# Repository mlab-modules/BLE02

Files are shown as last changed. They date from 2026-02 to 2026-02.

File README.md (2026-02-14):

# BLE02 - Dual-Mode Bluetooth HCI Controller

BLE02 is a dual-mode Bluetooth Low Energy controller module based on the CC2564C HCI compatible chipset.  
The module provides UART (HCI) and PCM/I²S digital audio interface and is designed as a compact MLAB building block for integration with external MCU/MPU systems.

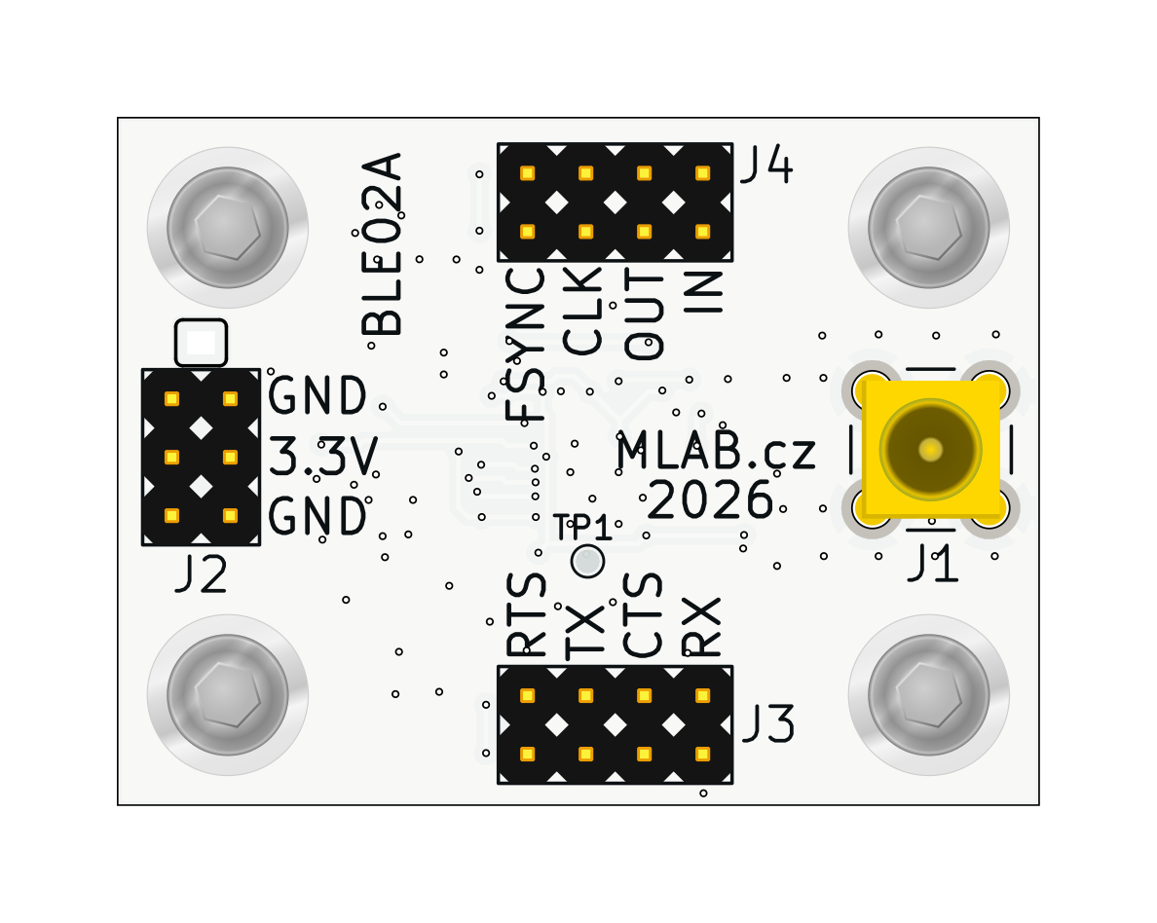
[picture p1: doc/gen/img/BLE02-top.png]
BLE02 top view


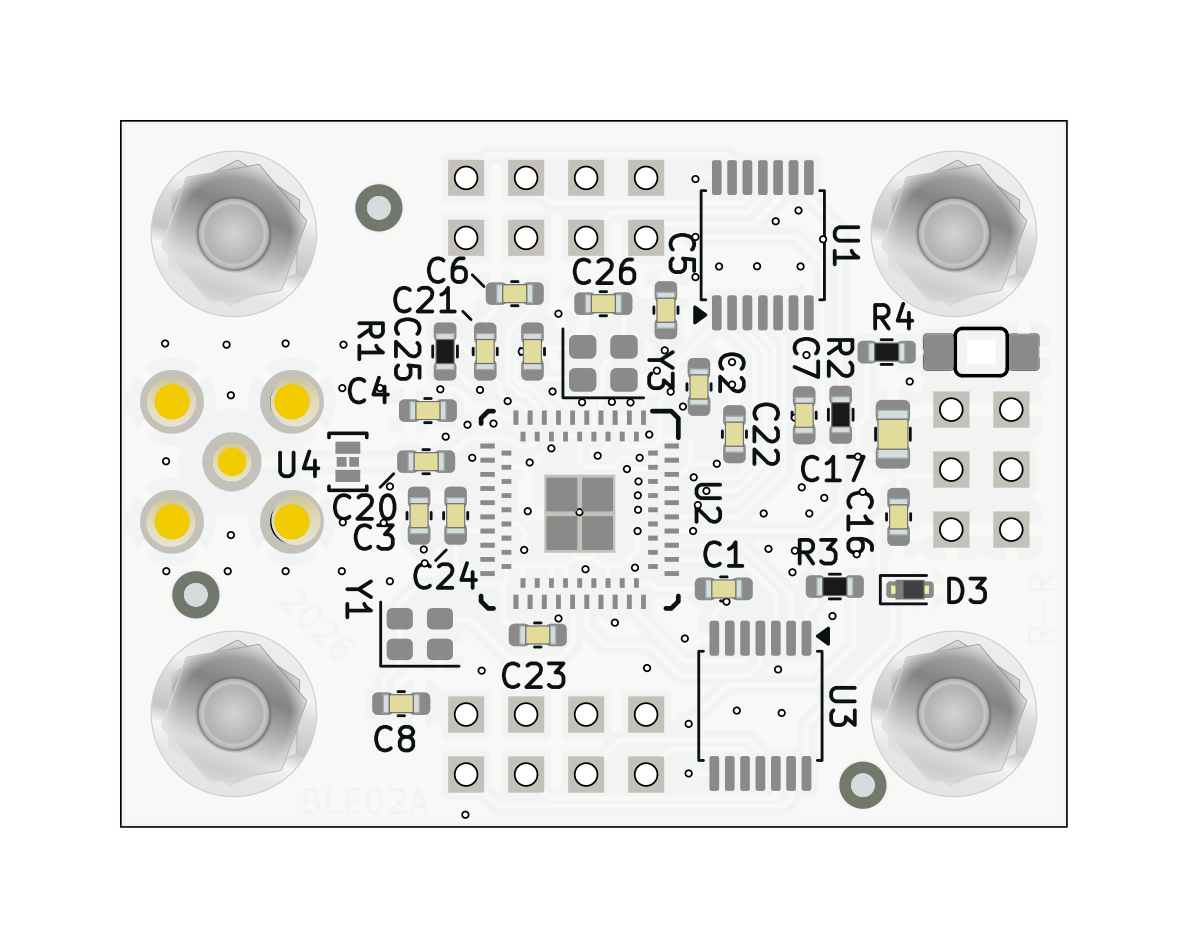
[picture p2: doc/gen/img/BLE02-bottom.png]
BLE02 bottom view


The RF section, clocks and power conditioning are implemented on-board. The host processor should handle the Bluetooth stack via HCI transport.

## Key Features

- Dual-mode Bluetooth controller (BR/EDR + LE, Bluetooth 5.1 compliant)
- HCI transport over UART (up to 4 Mbit/s)
- PCM / I²S digital audio interface
- Class 1 transmitter capability (up to +12 dBm)
- Integrated LDO regulator from 3.3V power source
- 26 MHz main crystal oscillator
- 32.768 kHz low-power clock oscillator
- 1.8 V I/O domain (level shifted to 3.3 V on module connectors)
- Single-ended 50 Ω RF interface on MCX connector

The module uses the chip in HCI mode. All higher Bluetooth layers must run on the host MCU.

## Electrical Parameters

### Supply

- **VCC (module input):** 3.3 V nominal
- On-board regulation:
  - CC2564C powered directly from power input
  - I/O domain: 1.8 V (generated internally, exposed as VDD_1V8)
- Typical consumption:
  - TX (GFSK, max power): ~100 mA
  - LE advertising: 200 µA average
  - Shutdown: less than 10 µA

## UART Interface (HCI)

- Transport: H4 (UART)
- Baud rate: 38.4 kbit/s to 4 Mbit/s
- Hardware flow control required (RTS/CTS)

The controller signals boot completion by asserting RTS low after reset.

## Audio Interface (PCM / I²S)

- PCM master or slave mode
- Up to 4.096 MHz bit clock
- Suitable for HFP, A2DP and other audio profiles

Note: Assisted modes (WBS, A2DP assist) cannot be used simultaneously with LE mode.

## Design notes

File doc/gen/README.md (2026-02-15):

# PCB

Board size: 40.13x29.97 mm (1.58x1.18 inches)

- This is the size of the rectangle that contains the board
- Thickness: 0.19 mm (7 mils)
- Material: FR4
- Finish: None
- Layers: 2
- Copper thickness: 35 µm

Solder mask: TOP / BOTTOM

- Color: Green

Silk screen: TOP / BOTTOM

- Color: White

Stackup:

Impedance controlled: YES

| Name | Type | Color | Thickness [µm]| Material | Er | Loss tan |
|---|---|---|---|---|---|---|
| F.SilkS | Top Silk Screen | | | | | |
| F.Paste | Top Solder Paste | | | | | |
| F.Mask | Top Solder Mask | Green | 10 | | | |
| F.Cu | copper | | 35 | | | |
| dielectric 1 | prepreg | | 100 | FR4 | 4.5 | 0.020 |
| B.Cu | copper | | 35 | | | |
| B.Mask | Bottom Solder Mask | Green | 10 | | | |
| B.Paste | Bottom Solder Paste  | | | | | |
| B.SilkS | Bottom Silk Screen | | | | | |

# Important sizes

Clearance: 0.13 mm (5 mils)

Track width: 0.13 mm (5 mils)

- By design rules: 0.13 mm (5 mils)

Drill: 0.3 mm (12 mils)

- Vias: 0.3 mm (12 mils) [Design: 0.3 mm (12 mils)]
- Pads: 1.0 mm (39 mils)
- The above values are real drill sizes, they add 0.1 mm (4 mils) to plated holes (PTH)

Via: 0.46/0.2 mm (18/8 mils)

- By design rules: 0.45/0.2 mm (18/8 mils)
- Micro via: yes [0.2/0.1 mm (8/4 mils)]
- Buried/blind via: yes
- Total: 97 (thru: 97 buried/blind: 0 micro: 0)

Outer Annular Ring: 0.08 mm (3 mils)

- By design rules: 0.08 mm (3 mils)

Eurocircuits class: 7E
- Using min drill 0.2 mm for an OAR of 0.13 mm

# General stats

Components count: (SMD/THT)

- Top: 0/8 (THT)
- Bottom: 32/0 (SMD)

Defined tracks:

- 0.13 mm (5 mils)
- 0.2 mm (8 mils)
- 0.25 mm (10 mils)
- 0.35 mm (14 mils)
- 0.4 mm (16 mils)

Used tracks:

- 0.13 mm (5 mils) (5) defined: yes
- 0.2 mm (8 mils) (381) defined: yes
- 0.25 mm (10 mils) (2) defined: yes
- 0.4 mm (16 mils) (2) defined: yes

Defined vias:

- 0.46/0.2 mm (18/8 mils)
- 0.8/0.2 mm (31/8 mils)

Used vias:

- 0.46/0.2 mm (18/8 mils) (Count: 97, Aspect: 0.4 A) defined: yes

Holes (excluding vias):

- 0.89 mm (35 mils) (22)
- 1.5 mm (59 mils) (1)
- 1.7 mm (67 mils) (4)
- 3.0 mm (118 mils) (4)

Oval holes:

Drill tools (including vias and computing adjusts and rounding):

- 0.3 mm (12 mils) (97)
- 1.0 mm (39 mils) (22)
- 1.6 mm (63 mils) (1)
- 1.8 mm (71 mils) (4)
- 3.1 mm (122 mils) (4)

Solder paste stats:

Using a paste with 87.75 % alloy, that has an specific gravity for the alloy of 7.4 g/cm³
and 1.0 g/cm³ for the flux. This paste has an specific gravity of  4.15 g/cm³.

The stencil thickness is  0.12 mm.

| Side | Pads with paste | Area [mm²] | Paste [g] |
|---|---|---|---|
| Total  | 162 | 72.36 | 0.36 |

Note: this is just an approximation to the theoretical value. Margins of the solder mask and waste aren't computed.

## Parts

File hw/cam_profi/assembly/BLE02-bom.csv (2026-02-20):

Component | Description | Part | References | Value | Footprint | Quantity Per PCB | Datasheet | ust_id | sim.pins
1 | Unpolarized capacitor, small symbol | C_Small | C25C26 | 10 pF | C_0603_1608Metric | 2 | ~ | 5c70984812875079b91f8be2
2 | Unpolarized capacitor, small symbol | C_Small | C20 | 22pF | C_0603_1608Metric | 1 | ~ | 5e3ff7af1287502a33bad770
3 | Unpolarized capacitor, small symbol | C_Small | C1C2C3C4C5C6C7C8C16C21C22C23C24 | 100nF | C_0603_1608Metric | 13 | ~ | 5c70984812875079b91f8bf2
4 | Unpolarized capacitor | C | C17 | 10uF | C_0805_2012Metric | 1 | ~ | 5c70984812875079b91f8bbe
5 | Zener diode | D_Zener | D3 | BZX585-B5V6.115 | D_SOD-523 | 1 | https://www.tme.eu/Document/7f59fc987b8fce7e4ab18399d6e66bd1/BZX585-DTE.pdf | 60879d38128750769ee58e48
6 | Light emitting diode | LED | D1 | LED | LED_1206_mill | 1 | ~ | 64ab2ec176c82a1d3b57875b | 1=K 2=A
7 | 2x03 2.54 mm pitch header, 2 pins next to each other are connected | HEADER_2x03_PARALLEL | J2 | 3.3V | Straight_2x03 | 1
8 | coaxial connector (BNC, SMA, SMB, SMC, Cinch/RCA, LEMO, ...) | Conn_Coaxial | J1 | Conn_Coaxial | MCX | 1 | ~ | 5fa10cc512875025b39779f6
9 | 2x04 2.54 mm pitch header, 2 pins next to each other are connected | HEADER_2x04_PARALLEL | J3J4 | JUMP_5X2 | Straight_2x04 | 2
10 |  | R-Device | R4 | 2k2 | R_0603_1608Metric | 1 | ~ | 5c70984512875079b91f895e
11 |  | R-Device | R1R2R3 | 10k | R_0603_1608Metric | 3 | ~ | 5c70984512875079b91f8962
12 |  | CC2564CRVMR | U2 | CC2564CRVMR | RVM0076A | 1 | https://www.ti.com/lit/gpn/cc2564c | 6998b45dd42e6e3c4d330db1
13 |  | LFB212G45CG1C187 | U4 | LFB212G45CG1C187 | Murata_C187 | 1 | https://pim.murata.com/asset/pim4/bandPassFilterBPF/LFB212G45CG1C187_PDF_BANDPASSFILTERBPF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 | 6998b530d42e6e3c4d330dd0
14 | Bidirectional level-shifting voltage translator, TSSOP-14 | TXS0104EPW | U1U3 | TXS0104EPW | TSSOP-14_4.4x5mm_P0.65mm | 2 | www.ti.com/lit/ds/symlink/txs0104e.pdf | 6998b3d2d42e6e3c4d330d92
15 | Four pin crystal, GND on pins 2 and 4, small symbol | Crystal_GND24_Small | Y3 | ECS-260-8-36CKM-TR | Crystal_SMD_2520-4Pin_2.5x2.0mm | 1 | https://eu.mouser.com/datasheet/3/294/1/ECX_2236.pdf | 6998b8c5d42e6e3c4d330e98
16 | 32.768kHz Crystal Oscillator (SPXO) | SG-3030CM | Y1 | LFSPXO009682 | Oscillator_SMD_SeikoEpson_SG210-4Pin_2.5x2.0mm | 1 | https://support.epson.biz/td/api/doc_check.php?mode=dl&lang=en&Parts=SG-3030CM | 6998b786d42e6e3c4d330e5b

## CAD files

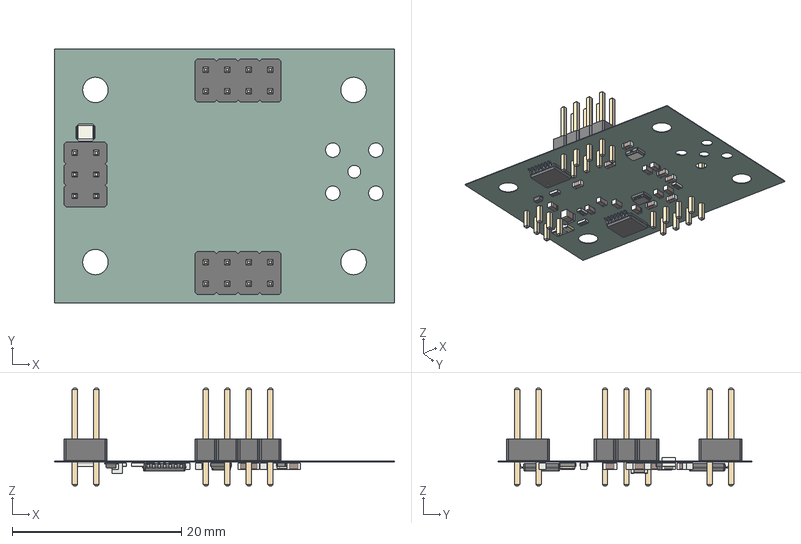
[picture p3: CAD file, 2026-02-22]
doc/gen/BLE02.step
40.1 x 30.0 x 11.5 mm
PinHeader_2x04_P2.54mm_Vertical x 2
PinHeader_2x03_P2.54mm_Vertical
C_0603_1608Metric x 16
Crystal_SMD_2520-4Pin_2.5x2.0mm
LED_1206_3216Metric
TSSOP-14_4.4x5mm_P0.65mm x 2
R_0603_1608Metric x 4
D_SOD-523
Oscillator_SMD_SeikoEpson_SG210-4Pin_2.5x2.0mm
C_0805_2012Metric
kibot_65nm3g8s_PCB

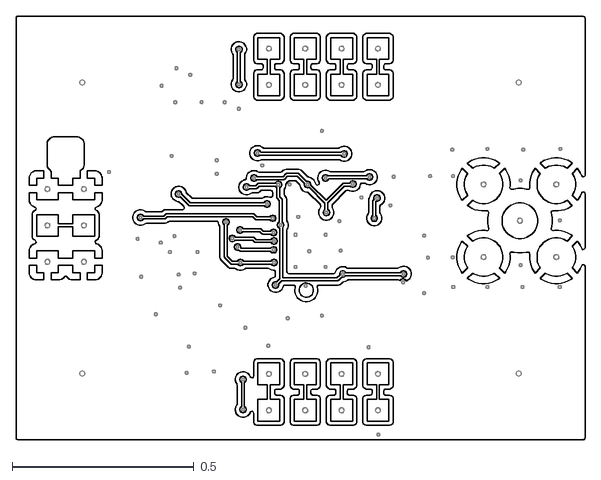
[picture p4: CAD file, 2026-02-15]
doc/gen/dxf/BLE02-F_Cu.dxf
1.56 x 1.16

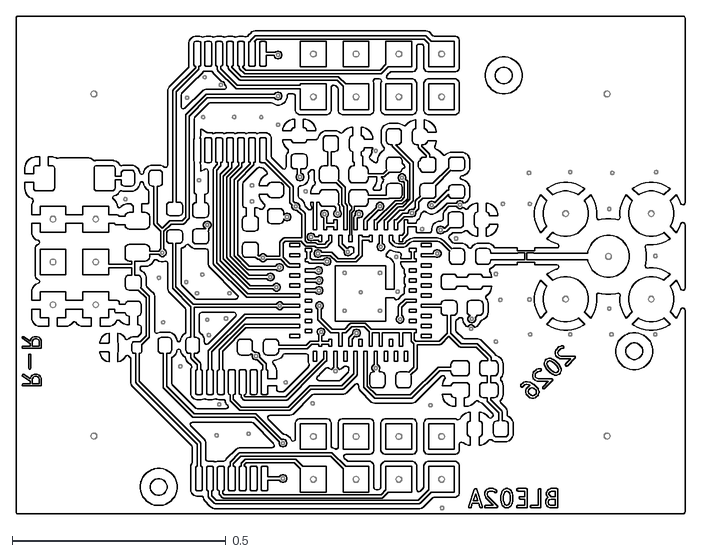
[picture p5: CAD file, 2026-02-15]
doc/gen/dxf/BLE02-B_Cu.dxf
1.56 x 1.16

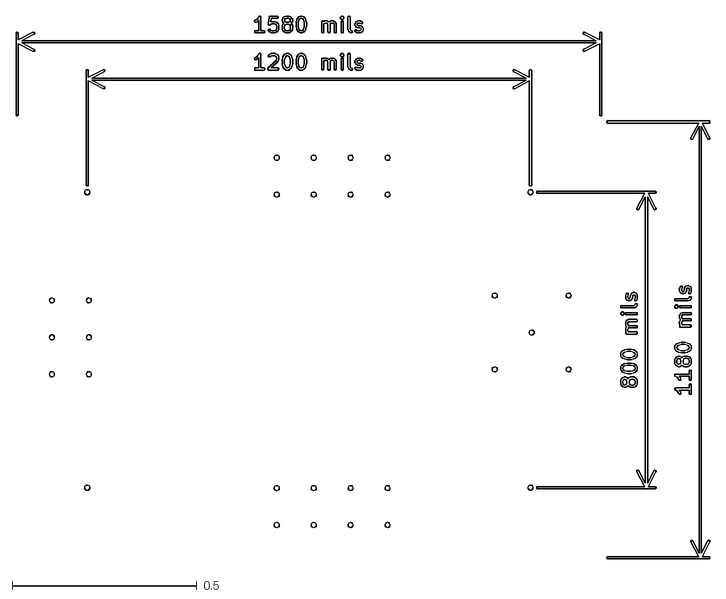
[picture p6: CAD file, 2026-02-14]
doc/gen/dxf/BLE02-User_Comments.dxf
1.88 x 1.47

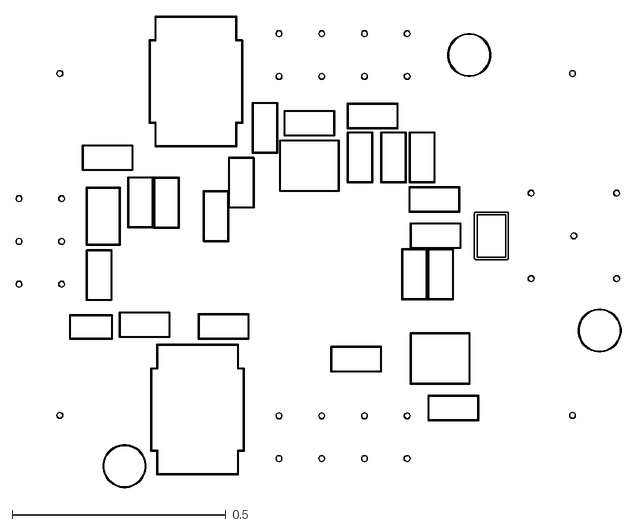
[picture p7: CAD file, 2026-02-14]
doc/gen/dxf/BLE02-B_Courtyard.dxf
1.42 x 1.10

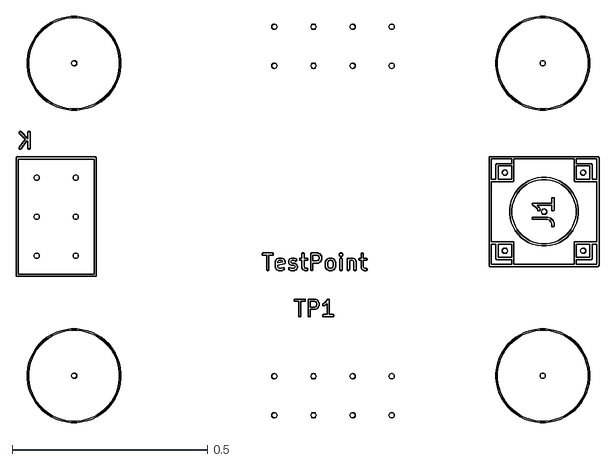
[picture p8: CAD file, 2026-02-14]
doc/gen/dxf/BLE02-F_Fab.dxf
1.49 x 1.04

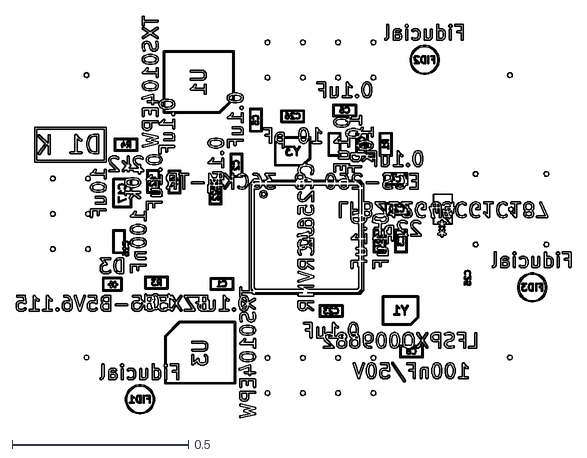
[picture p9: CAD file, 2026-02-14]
doc/gen/dxf/BLE02-B_Fab.dxf
1.57 x 1.14

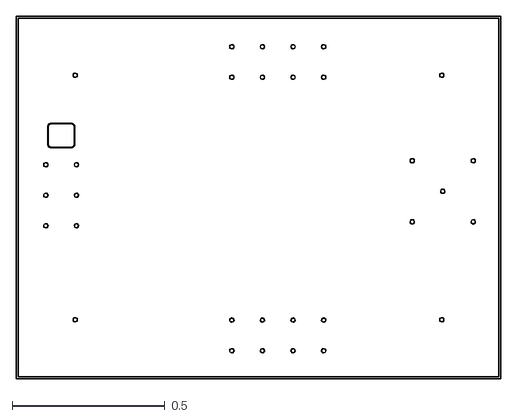
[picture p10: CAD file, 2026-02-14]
doc/gen/dxf/BLE02-Edge_Cuts.dxf
1.59 x 1.19

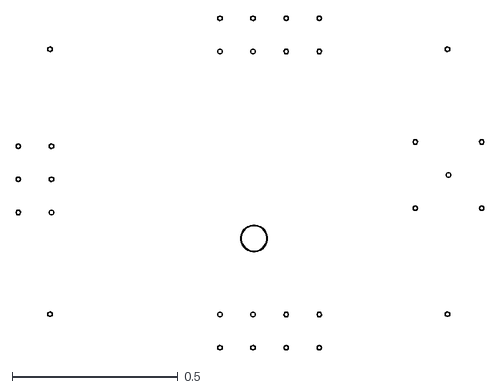
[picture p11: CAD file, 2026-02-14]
doc/gen/dxf/BLE02-F_Courtyard.dxf
1.41 x 1.01

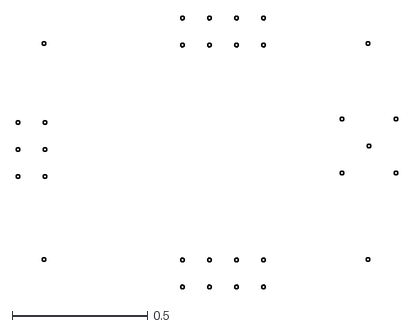
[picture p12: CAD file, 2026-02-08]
doc/gen/dxf/BLE02-User_Eco2.dxf
1.41 x 1.01

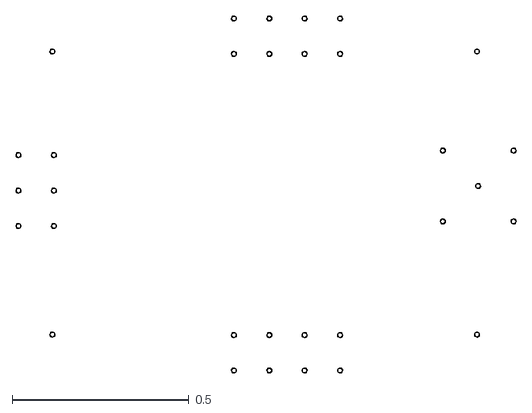
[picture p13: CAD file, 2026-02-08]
doc/gen/dxf/BLE02-F_Adhesive.dxf
1.41 x 1.01

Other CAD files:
doc/gen/dxf/BLE02-B_Mask.dxf
doc/gen/dxf/BLE02-B_Paste.dxf
doc/gen/dxf/BLE02-B_Silkscreen.dxf
doc/gen/dxf/BLE02-F_Mask.dxf
doc/gen/dxf/BLE02-F_Silkscreen.dxf

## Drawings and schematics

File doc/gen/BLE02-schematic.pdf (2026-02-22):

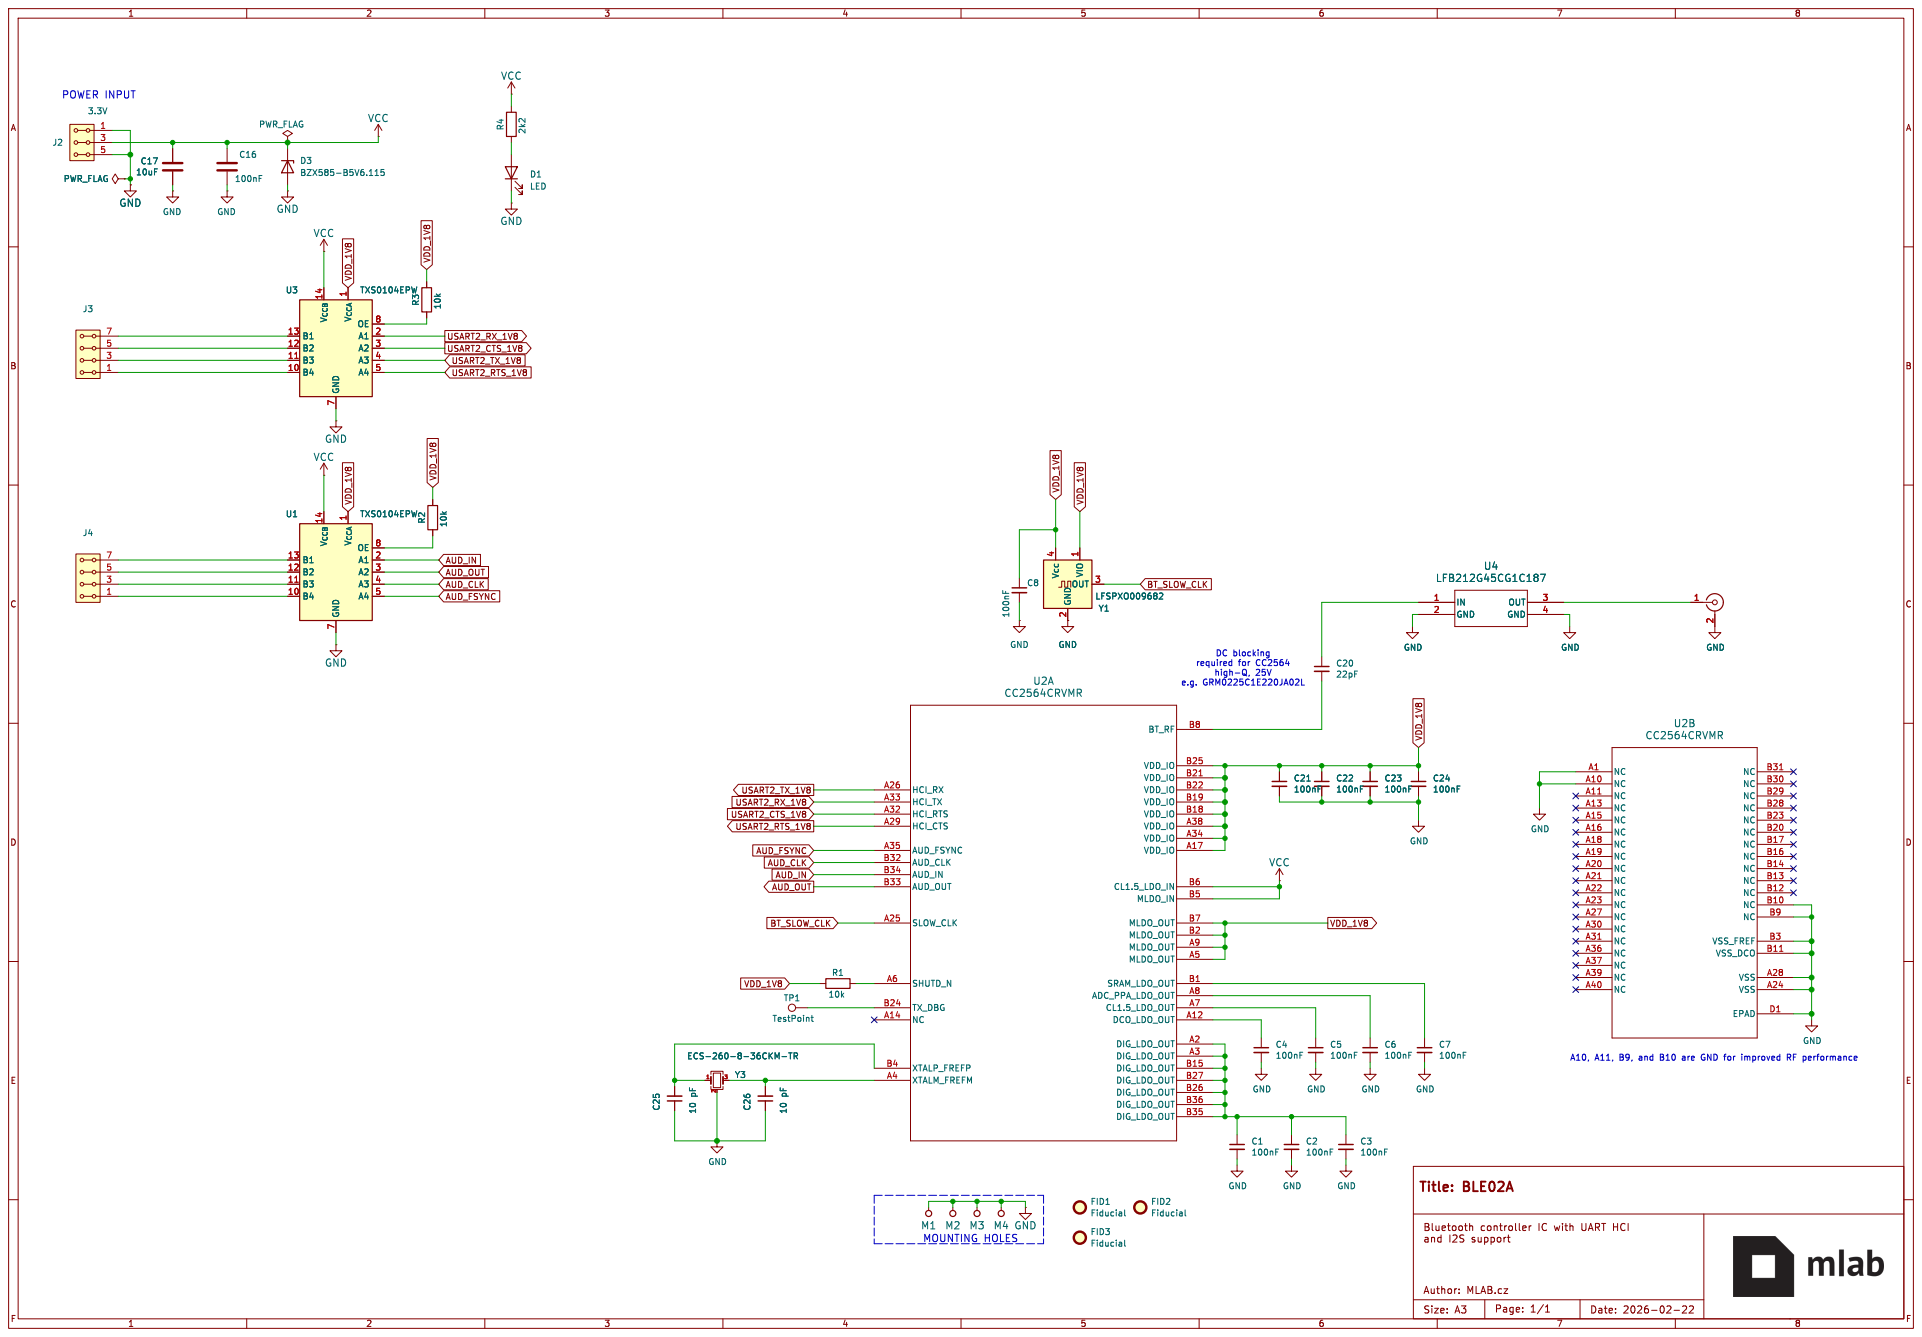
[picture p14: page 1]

1 OUT 3 GND R3 10k C25 10 pF Y3 ECS-260-8-36CKM-TR

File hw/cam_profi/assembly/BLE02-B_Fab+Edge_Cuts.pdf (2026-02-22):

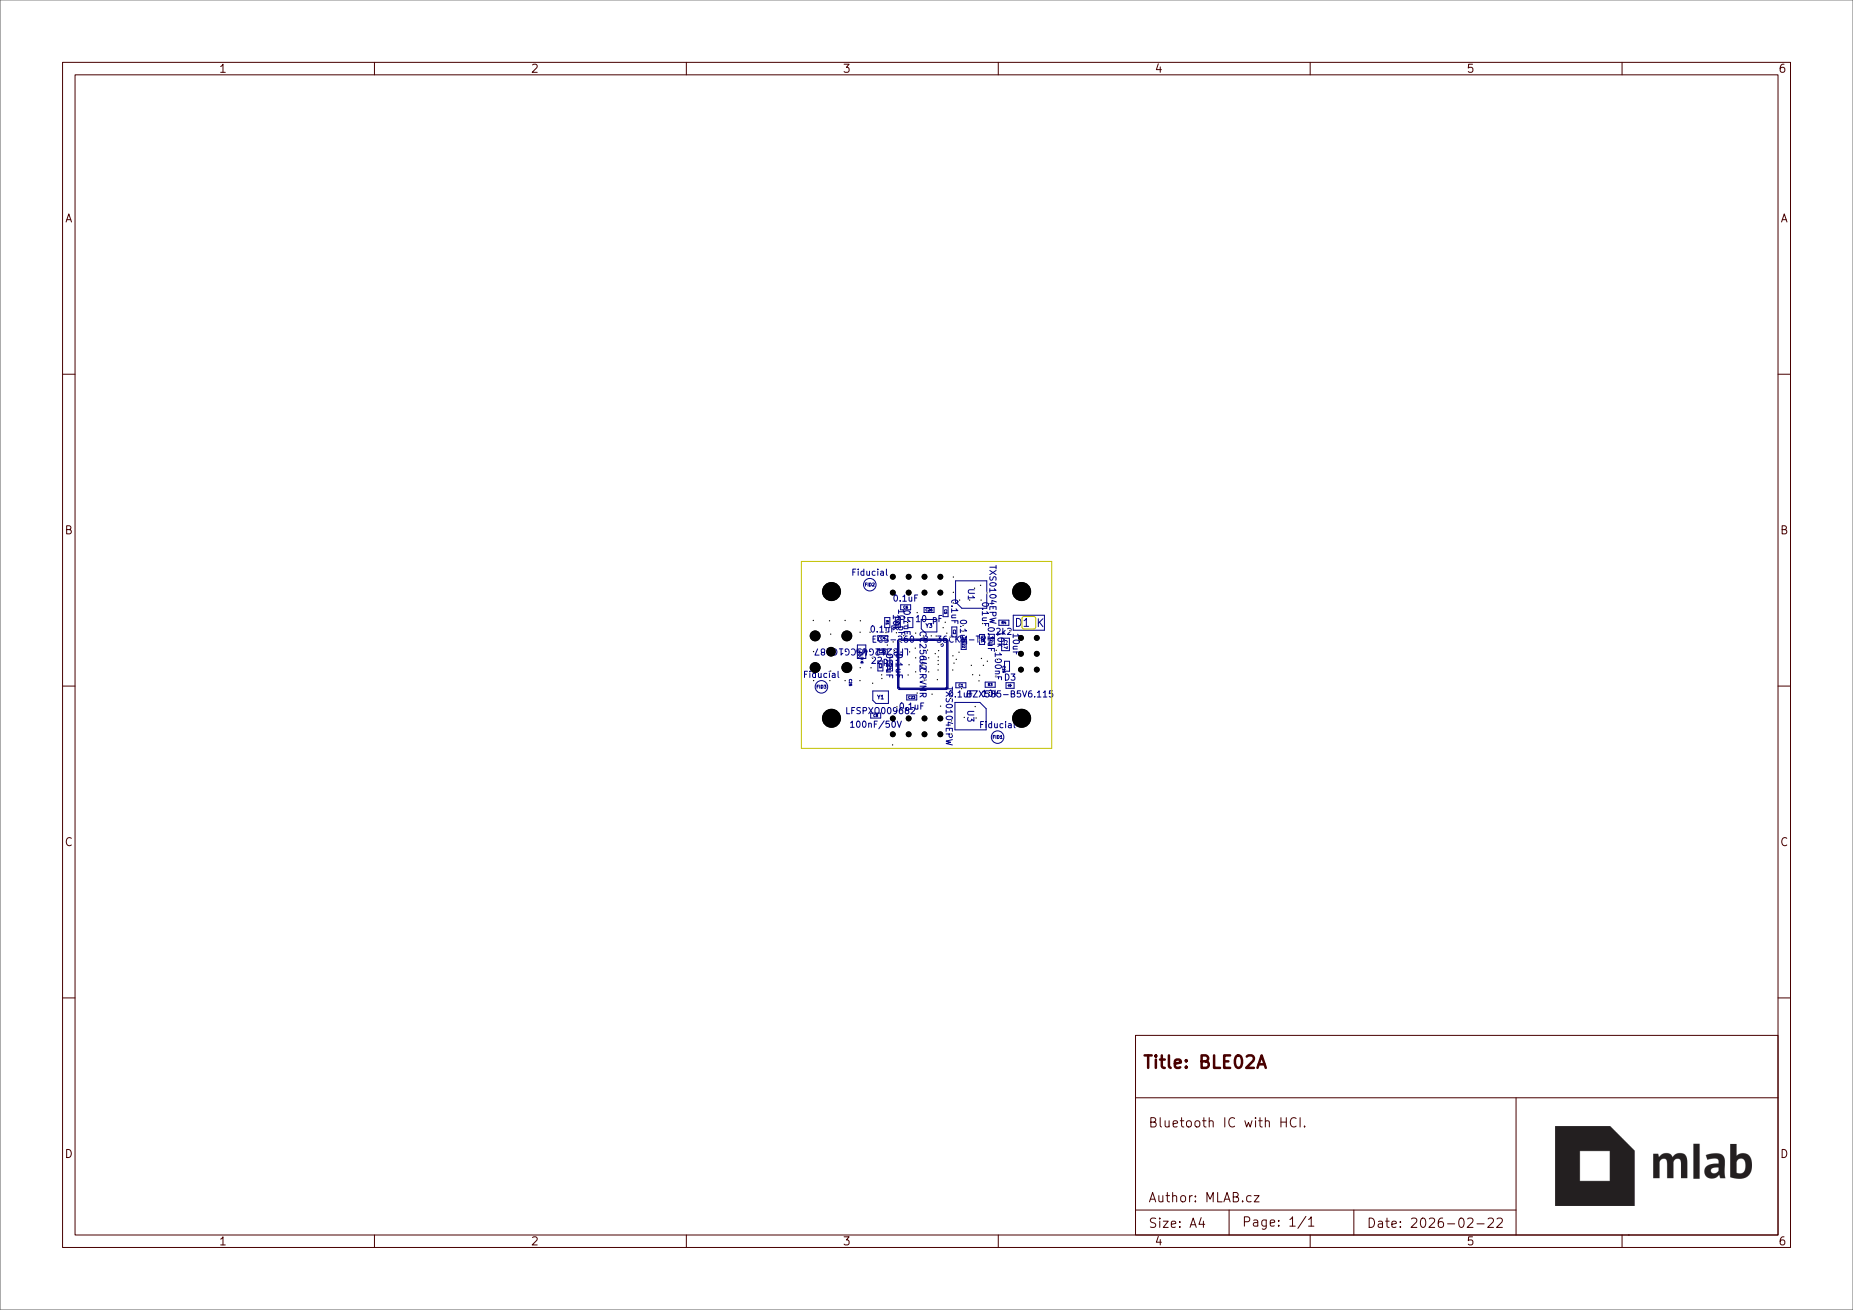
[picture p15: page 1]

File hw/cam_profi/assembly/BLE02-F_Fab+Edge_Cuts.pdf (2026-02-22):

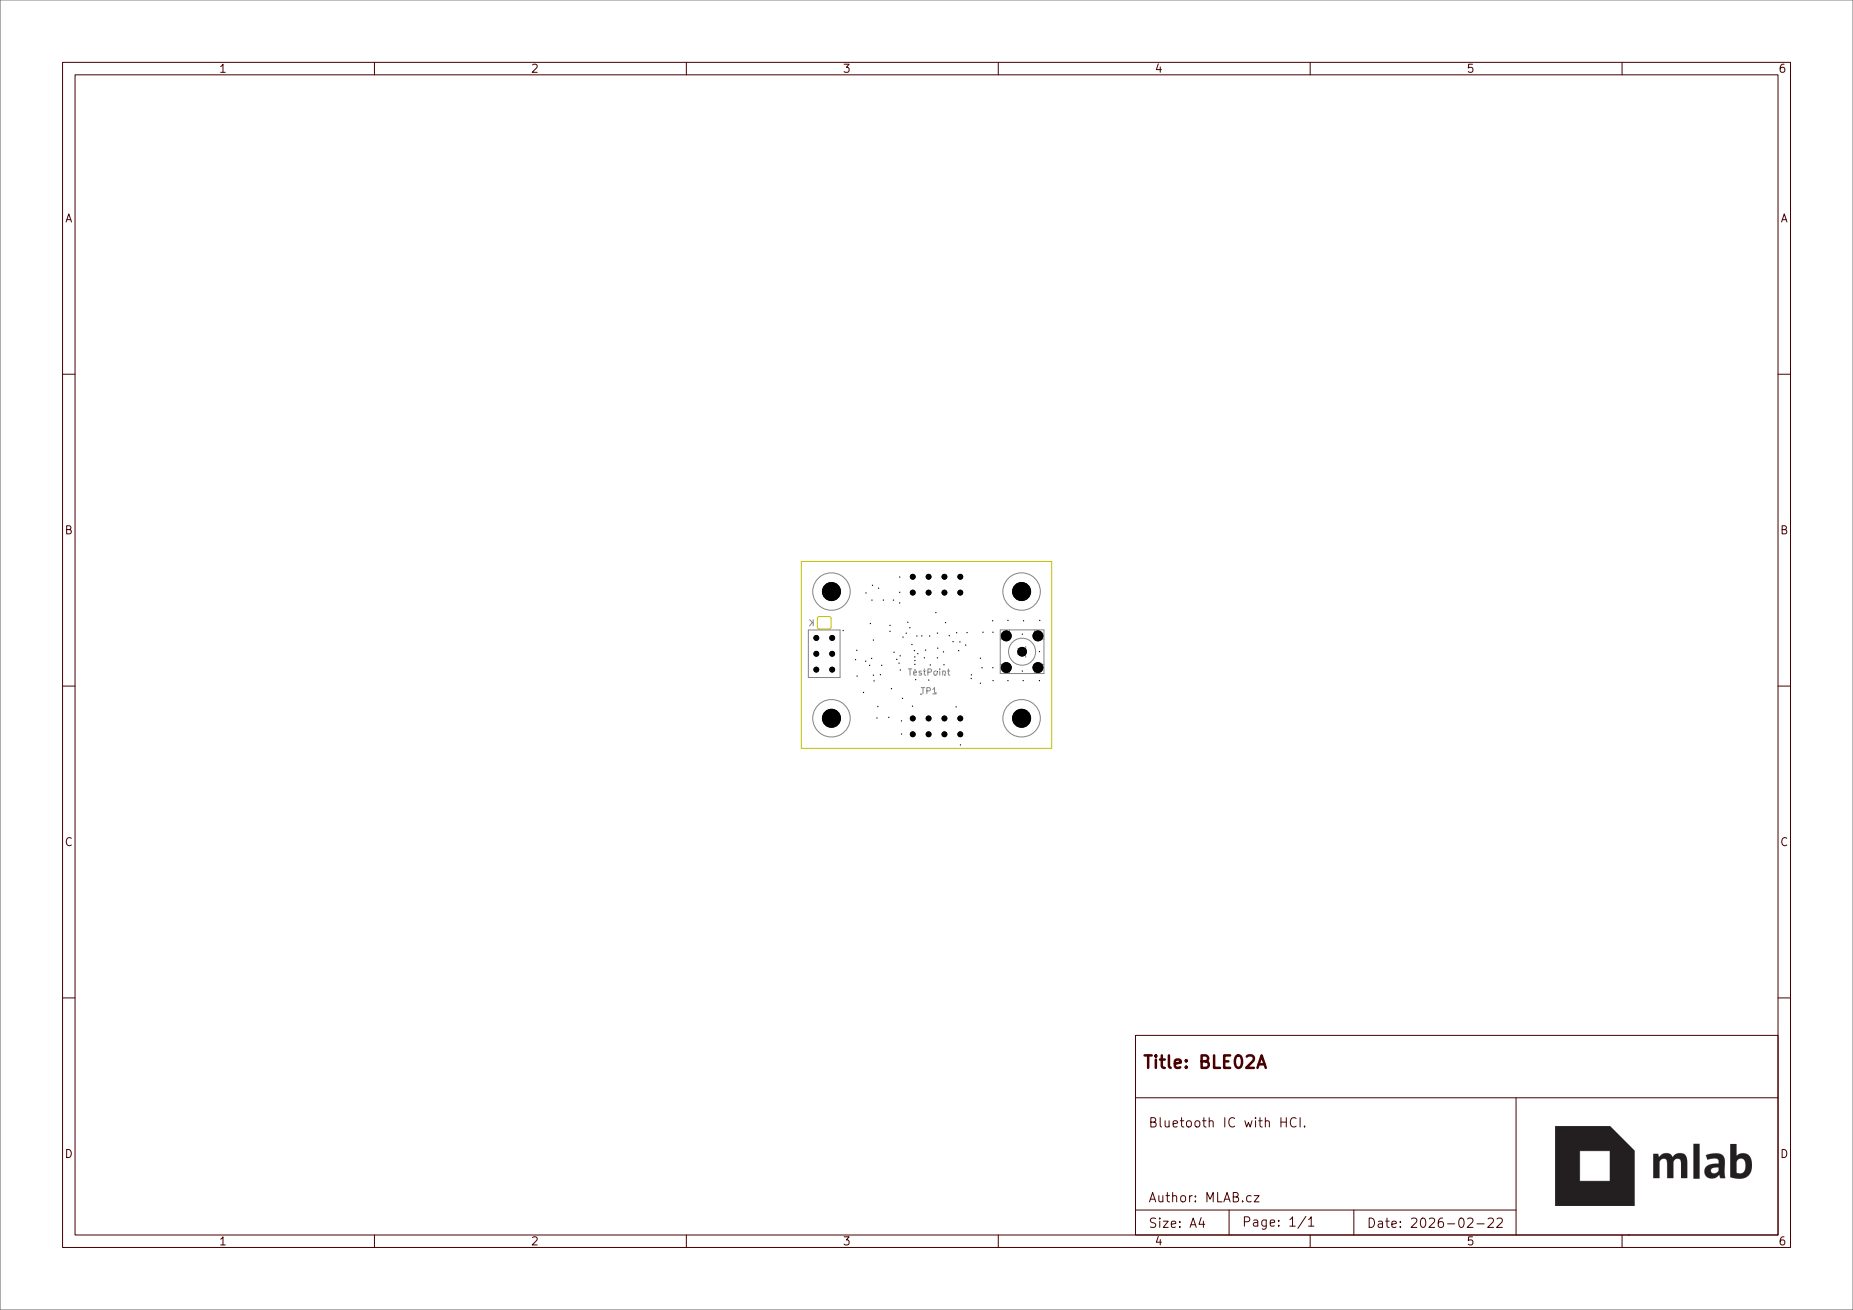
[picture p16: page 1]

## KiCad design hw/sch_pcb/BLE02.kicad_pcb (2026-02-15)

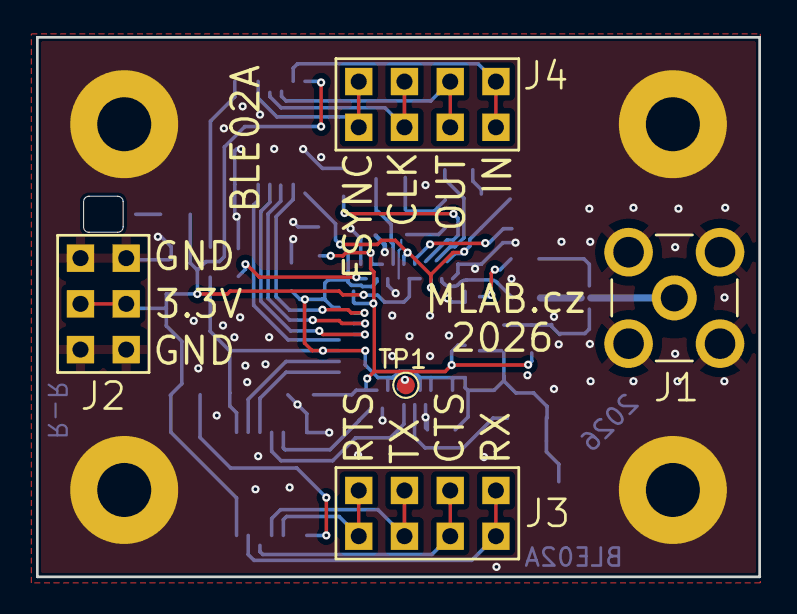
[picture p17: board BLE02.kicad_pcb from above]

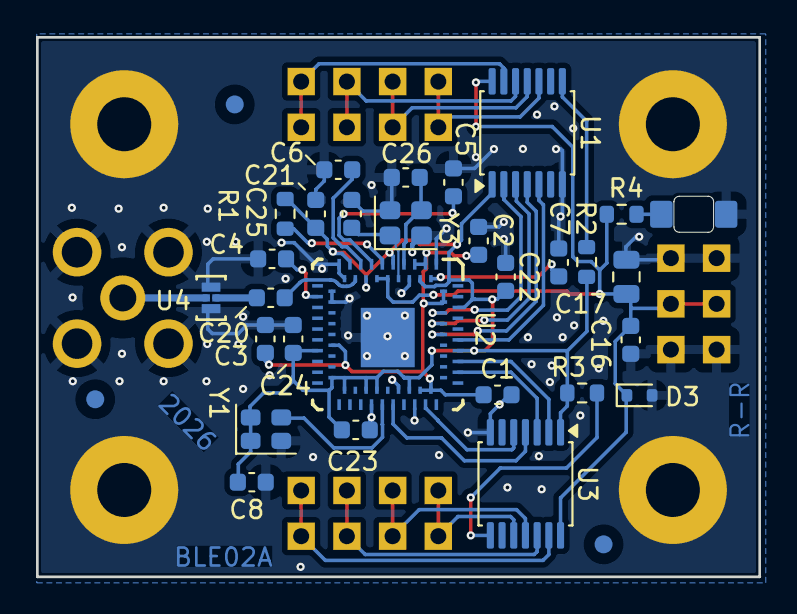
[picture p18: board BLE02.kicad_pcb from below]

Board: 2 copper layers, 40.1 x 30.0 mm, 41 parts (32 on the bottom side), 35 nets.

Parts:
C1, C2, C3, C4, C5, C6, C7, C21, C22, C23, C24: 0.1uF; C_0603_1608Metric
C8: 100nF/50V; C_0603_1608Metric
C16: 100nF; C_0603_1608Metric
C17: 10uF; C_0805_2012Metric
C20: 22pF; C_0603_1608Metric
C25, C26: 10 pF; C_0603_1608Metric
D1: LED; LED_1206_mill
D3: BZX585-B5V6.115; D_SOD-523
FID1, FID2, FID3: Fiducial; Fiducial_1mm_Mask2mm
J1: Conn_Coaxial; MCX
J2: 3.3V; Straight_2x03
J3, J4: JUMP_5X2; Straight_2x04
M1, M2, M3, M4: HOLE; MountingHole_3mm
R1, R2, R3: 10k; R_0603_1608Metric
R4: 2k2; R_0603_1608Metric
TP1: TestPoint; TestPoint_Pad_D1.0mm
U1, U3: TXS0104EPW; TSSOP-14_4.4x5mm_P0.65mm
U2: CC2564CRVMR; RVM0076A
U4: LFB212G45CG1C187; Murata_C187
Y1: LFSPXO009682; Oscillator_SMD_SeikoEpson_SG210-4Pin_2.5x2.0mm
Y3: ECS-260-8-36CKM-TR; Crystal_SMD_2520-4Pin_2.5x2.0mm

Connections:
AUD_CLK: U1.4 (A3), U2.B32 (AUD_CLK)
AUD_FSYNC: U1.5 (A4), U2.A35 (AUD_FSYNC)
AUD_IN: U1.2 (A1), U2.B34 (AUD_IN)
AUD_OUT: U1.3 (A2), U2.B33 (AUD_OUT)
BT_SLOW_CLK: U2.A25 (SLOW_CLK), Y1.3 (OUT)
GND: C1.2, C2.2, C3.2, C4.2, C5.2, C6.2, C7.2, C8.2, C16.2, C17.2, C21.2, C22.2, C23.2, C24.2, C25.1, C26.1, D1.1 (K), D3.2 (A), J1.2 (Ext), J2.1, J2.2, J2.5, J2.6, M1.1, M2.1, M3.1, M4.1, U1.7 (GND), U2.A1 (NC), U2.A10 (NC), U2.A24 (VSS), U2.A28 (VSS), U2.B3 (VSS_FREF), U2.B9 (NC), U2.B10 (NC), U2.B11 (VSS_DCO), U2.D1 (EPAD), U3.7 (GND), U4.2 (GND), U4.4 (GND), Y1.2 (GND), Y3.2 (G), Y3.4 (G)
unnamed: C1.1, C2.1, C3.1, U2.A2 (DIG_LDO_OUT), U2.A3 (DIG_LDO_OUT), U2.B15 (DIG_LDO_OUT), U2.B26 (DIG_LDO_OUT), U2.B27 (DIG_LDO_OUT), U2.B35 (DIG_LDO_OUT), U2.B36 (DIG_LDO_OUT)
unnamed: D1.2 (A), R4.2
unnamed: J1.1 (In), U4.3 (OUT)
unnamed: J4.7, J4.8, U1.13 (B1)
unnamed: J4.5, J4.6, U1.12 (B2)
unnamed: J4.3, J4.4, U1.11 (B3)
unnamed: J4.1, J4.2, U1.10 (B4)
unnamed: R2.2, U1.8 (OE)
unnamed: C6.1, U2.A8 (ADC_PPA_LDO_OUT)
unnamed: C20.2, U2.B8 (BT_RF)
unnamed: C5.1, U2.A7 (CL1.5_LDO_OUT)
unnamed: C4.1, U2.A12 (DCO_LDO_OUT)
unnamed: R1.1, U2.A6 (SHUTD_N)
unnamed: C7.1, U2.B1 (SRAM_LDO_OUT)
unnamed: TP1.1, U2.B24 (TX_DBG)
unnamed: C26.2, U2.A4 (XTALM_FREFM), Y3.3
unnamed: C25.2, U2.B4 (XTALP_FREFP), Y3.1
unnamed: J3.7, J3.8, U3.13 (B1)
unnamed: J3.5, J3.6, U3.12 (B2)
unnamed: J3.3, J3.4, U3.11 (B3)
unnamed: J3.1, J3.2, U3.10 (B4)
unnamed: R3.2, U3.8 (OE)
unnamed: C20.1, U4.1 (IN)
USART2_CTS_1V8: U2.A32 (HCI_RTS), U3.3 (A2)
USART2_RTS_1V8: U2.A29 (HCI_CTS), U3.5 (A4)
USART2_RX_1V8: U2.A33 (HCI_TX), U3.2 (A1)
USART2_TX_1V8: U2.A26 (HCI_RX), U3.4 (A3)
VCC: C16.1, C17.1, D3.1 (K), J2.3, J2.4, R4.1, U1.14 (V_{CCB}), U2.B5 (MLDO_IN), U2.B6 (CL1.5_LDO_IN), U3.14 (V_{CCB})
VDD_1V8: C8.1, C21.1, C22.1, C23.1, C24.1, R1.2, R2.1, R3.1, U1.1 (V_{CCA}), U2.A5 (MLDO_OUT), U2.A9 (MLDO_OUT), U2.A17 (VDD_IO), U2.A34 (VDD_IO), U2.A38 (VDD_IO), U2.B2 (MLDO_OUT), U2.B7 (MLDO_OUT), U2.B18 (VDD_IO), U2.B19 (VDD_IO), U2.B21 (VDD_IO), U2.B22 (VDD_IO), U2.B25 (VDD_IO), U3.1 (V_{CCA}), Y1.1 (VIO), Y1.4 (Vcc)

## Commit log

2026-01-22 Commiting modified design from https://github.com/mattkelly/stm32-cc2564-board
    [BLE02.kicad_pcb, BLE02.kicad_sch]
2026-01-22 Update actions products
    [BLE02-B_Adhesive.dxf, BLE02-B_Courtyard.dxf, BLE02-B_Cu.dxf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]
2026-02-08 Connectors placement on the board
    [BLE02.kicad_pcb, BLE02.kicad_sch, connectors.kicad_sch]
2026-02-08 Update project workflows.
    [BLE02.kicad_sch, connectors.kicad_sch]
2026-02-08 Fix footprint of pin-headers.
    [BLE02.kicad_pcb, BLE02.kicad_sch, connectors.kicad_sch]
2026-02-08 Add text for connectors
    [BLE02.kicad_pcb, BLE02.kicad_sch, connectors.kicad_sch]
2026-02-08 Connect B10 to gnd
    [BLE02.kicad_pcb, BLE02.kicad_sch]
2026-02-10 Improve layout.
    [BLE02.kicad_pcb]
2026-02-14 Cleanup layout. Fix obsolete part types.
    [BLE02.kicad_pcb, BLE02.kicad_sch, connectors.kicad_sch]
2026-02-14 Cleanup and update documentation.
    [BLE02.kicad_pcb]
2026-02-15 Automatic update of KiCAD outputs
    [BLE02.step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]
2026-02-15 Cleanup layout and silkscreen.
    [BLE02.kicad_pcb]
2026-02-20 Update UST_IDs.
    [BLE02.kicad_sch, connectors.kicad_sch]
